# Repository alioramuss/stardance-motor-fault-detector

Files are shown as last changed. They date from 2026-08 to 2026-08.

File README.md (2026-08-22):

# Motor Fault Detector

An edge-AI predictive maintenance system. An accelerometer on a small motor
streams vibration to a laptop, where a machine-learning model decides in real
time whether the motor is running healthy or has developed a fault.

Built for the [Stardance Challenge 2026](https://stardance.hackclub.com)
(NASA × Hack Club × AMD × GitHub).

---

## The problem

When a motor develops a mechanical fault — a bearing wearing out, a rotor going
out of balance — it changes how it vibrates long before it fails. Industry
catches this with condition monitoring: sensors on the machine, software
watching for the signature of a fault. The equipment that does it costs
thousands.

This is the same idea for about £15, using a hobbyist accelerometer and a
laptop.

---

## Hardware

| Part | Role |
|---|---|
| Arduino Uno Rev3 | Samples the sensor and streams over USB |
| MPU-6050 (GY-521) | 3-axis accelerometer, ±2 g range, 16384 counts per g |
| USB desk fan | The motor under test |
| Breadboard + jumpers | |

Wiring — the Uno's I²C lives on A4/A5 and cannot be moved:

| MPU-6050 | Uno |
|---|---|
| VCC | 5V |
| GND | GND |
| SDA | A4 |
| SCL | A5 |

**Fault injection.** A small weight taped to one fan blade creates a rotor
imbalance — the most common mechanical fault in rotating machinery, and one
that produces a clear vibration signature at the rotation frequency.

**Sensor mounting.** The MPU-6050 is fixed to the fan body with double-sided
tape rather than a printed bracket. This is a known weakness: the sensor's
position shifted between the first two recordings, which is why the healthy and
faulty datasets are not perfectly comparable. A printed holder is planned, and
would be the single biggest improvement to data quality.

A full CAD assembly of the build is in [`CAD/`](CAD/), as STEP and STL.

---

## How it works

```
MPU-6050 ──I²C──> Arduino Uno ──USB serial──> browser
  200 Hz            timestamped CSV            ├─ 1 s rolling window
                    115200 baud                ├─ spectral features (FFT)
                                               ├─ neural network
                                               └─ HEALTHY / FAULT
                                                        │
                              LED alarm <──serial───────┘
```

The Uno does no inference. With 2 KB of RAM it cannot hold a neural network, so
it acts purely as a sensor node — a real constraint that shaped the design, not
a shortcut.

### Sampling

`firmware/motor_sensor.ino` samples all three axes at a fixed **200 Hz** and
prints `timestamp,ax,ay,az` at 115200 baud. The loop is timed with `micros()`
rather than `delay()` so the interval stays constant; the FFT downstream is
meaningless if the sample rate wanders.

200 Hz gives 100 Hz of usable bandwidth, comfortably above the fan's ~37.5 Hz
rotation frequency.

### Data collection

`tools/capture.ps1` reads the serial port and writes CSV. No extra software is
required — it uses `System.IO.Ports`, which ships with Windows.

Two 60-second recordings, 12,000 samples each: fan normal, and fan with the
weight attached. Each was split into twelve 5-second files so the training and
test sets could be split at the sample level.

### Features and model

Built in [Edge Impulse](https://edgeimpulse.com):

| Setting | Value |
|---|---|
| Window | 1000 ms |
| Stride | 500 ms (50% overlap) |
| Processing | Spectral Analysis, FFT length 64 |
| Classifier | Dense network, 111 input features |
| Training windows | 170 (90 faulty, 80 healthy) |

Spectral Analysis matters here for a specific reason: it removes the DC
component before the FFT. Without that, the model could learn *which way the
sensor is tilted* — gravity dominates the raw signal at roughly 16,000 counts,
while the vibration is a few thousand. Stripping DC forces it to use the
frequency content, which is what a fault actually changes.

### Deployment

The model is exported as a **WebAssembly** build and runs in the browser. The
dashboard reads the serial port directly through the Web Serial API, so
inference happens on the same machine with no server and no cloud call.

---

## Results

### Fan rotation frequency

The FFT shows a clear peak at **37.5 Hz — about 2,250 rpm.** The fan's speed,
measured with an accelerometer and some maths rather than a tachometer.

### Raw separation, before any ML

Standard deviation of the X axis:

| Condition | sd (counts) |
|---|---|
| Healthy | 2,507 |
| Imbalanced | 3,875 |

A 55% increase. The fault is visible in the raw data before a model touches it,
which is the right thing to check first.

### Classifier

| | Accuracy |
|---|---|
| First attempt, unnormalised features | 64.7% |
| With StandardScaler + 100 training cycles | 100% |
| Held-out test set | 5/5 samples, 44/44 windows |

The first attempt failed in an informative way: it classified almost everything
as faulty. The features range from log-spectral values near 6 to RMS values in
the thousands, and a network fed inputs on wildly different scales struggles to
converge. Normalising fixed it completely.

### Live performance

| Metric | Value |
|---|---|
| Sample rate sustained | 200/sec |
| Inference time | 0.3 ms |
| Decision latency | ~1 s (one window) |

---

## Honest limitations

**The 100% is not as good as it looks.** Both classes came from a single
continuous recording each. The training and test windows are therefore
near-neighbours from the same session — same fan, same position, same
afternoon. The test set measures whether the pipeline works, not whether the
model generalises.

In live use it detects the fault reliably but not every single time. That gap
between 100% on paper and imperfect in practice is the honest result, and it
comes directly from the single-session dataset.

**Two classes forces a choice.** Shown something it has never seen — a shaken
fan, a different motor, a fan switched off — the model must still answer
"healthy" or "faulty". It cannot say "this is something else". A real system
needs an anomaly class or a rejection threshold.

**One fault type, one machine.** Rotor imbalance on one USB fan. Nothing here
demonstrates transfer to bearing wear, or to a different motor.

### What would fix it

- Record many short sessions across different days, fan speeds and sensor
  placements, instead of one long one
- Add a "motor off" class so the model can't win by detecting whether the fan
  is running
- Add a second fault type — a rubbing or obstructed blade
- Measure the live detection rate properly: apply the fault N times, count how
  many are caught

---

## Running it

### Collect data

```powershell
# fan running in the condition you want to record
.\tools\capture.ps1 -Label healthy -Seconds 60
```

Writes `data/healthy.1.csv` … `data/healthy.12.csv`. Run it again with
`-Label faulty` after taping a small weight to one blade.

### Live detection

```powershell
cd model\browser
node serve.js
```

Then open `http://localhost:8000/live.html` in Chrome or Edge and click
**Connect Arduino**. Close the Arduino IDE's Serial Monitor first — only one
program can hold the port.

The dashboard shows the verdict and confidence, a live FFT spectrum with the
rotation peak marked, the vibration waveform with gravity removed, a history
strip of recent predictions, and an adjustable alarm threshold.

### Alarm threshold

The slider sets how much evidence is needed before declaring a fault, with
15 points of hysteresis so a marginal signal cannot flicker. Lower it and faults
are caught earlier at the cost of occasional false alarms — usually the right
trade for an alarm, since a missed failure costs more than a false one. Where
that line goes is an engineering decision, not something the model decides.

---

## Build notes

A few things that cost real time and might save someone else some.

**The Edge Impulse CLI will not install on Windows ARM64.** `npm install -g
edge-impulse-cli` fails because node-gyp cannot find a C++ compiler, and it
installs a broken shell that fails at runtime with MODULE_NOT_FOUND. Rather
than install several gigabytes of Visual Studio Build Tools, this project routes
around it entirely: CSVs are uploaded through Edge Impulse Studio's browser
uploader, and the model is deployed as WebAssembly instead of a compiled
library. Nothing is lost, and the whole toolchain stays compiler-free.

**Byte order in the accelerometer read.** The common Arduino idiom
`Wire.read() << 8 | Wire.read()` does not guarantee which `read()` executes
first, so it can silently return byte-swapped values. Reading each byte into its
own variable removes the gamble.

**Edge Impulse infers labels from filenames** up to the first dot, so
`healthy.1.csv` lands as *healthy*. Splitting each recording into numbered
chunks gives both automatic labelling and enough samples to split train/test.

---

## Repository

```
CAD/                      full assembly, STEP and STL
PCB/                      wiring diagram (no custom board — breadboard build)
firmware/                 Arduino sketch — samples at 200 Hz, drives the LED alarm
tools/capture.ps1         serial to CSV logger
data/                     recorded datasets, 5-second chunks
model/browser/            exported WebAssembly model, live dashboard, local server
docs/wiring.svg           wiring diagram
devlogs/                  build log
experiments/ultrasonic/   parked HC-SR04 non-contact sensing experiment
BOM.csv                   parts in the build
BOM-funding.csv           parts requested for the next phase
```

The `experiments/` folder is work that didn't make it into the main result —
kept because the reasoning is useful, and the write-up in
`experiments/ultrasonic/rig-design.md` explains why the approach hits a hard
physical limit.

---

## Licence

MIT.

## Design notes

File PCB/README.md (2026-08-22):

# PCB

**There is no custom PCB in this project.**

The build uses an Arduino Uno Rev3 with an MPU-6050 breakout module on a
solderless breadboard, so there are no board source files to publish. This
folder holds the wiring diagram instead, which serves the same purpose — it
shows exactly how the circuit is connected so someone can reproduce it.

`wiring-diagram.svg` — MPU-6050 to Arduino Uno.

| MPU-6050 | Uno | Note |
|---|---|---|
| VCC | 5V | via the breadboard's + rail |
| GND | GND | via the breadboard's − rail |
| SDA | A4 | I²C, fixed on the Uno |
| SCL | A5 | I²C, fixed on the Uno |

The only soldering in the build is the 8-way pin header onto the MPU-6050
module. The long side of the header goes into the breadboard.

A custom PCB would be a reasonable next step — it would remove the breadboard
as a source of intermittent contacts and let the sensor be mounted rigidly,
which is the main weakness of the current build.

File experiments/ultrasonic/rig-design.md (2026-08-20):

# Non-contact sensing experiment — design notes

**Question.** The MPU-6050 detects fan imbalance reliably, but it has to be
bolted to the machine. Can a £2 HC-SR04 ultrasonic rangefinder detect the same
fault without touching anything — and if so, at what angle and standoff?

**Why it's worth doing.** Contact sensors are the standard answer in condition
monitoring, but they need mounting, wiring and access. Non-contact sensing is
the interesting frontier, and knowing precisely *where a cheap sensor stops
working* is a legitimate result. This experiment can fail and still be worth
writing up — as long as the failure is characterised rather than hand-waved.

---

## The honest physics, up front

Work out whether this can possibly succeed before running it, because the answer
shapes what you measure.

**Sample rate.** The HC-SR04 needs roughly 40–60 ms between triggers or the
previous echo is still ringing when the next arrives. That caps you at about
**25 Hz**. Your fan spins at **37.5 Hz**.

Nyquist says you need to sample above 75 Hz to reconstruct a 37.5 Hz signal.
You are sampling at a third of that. The wobble will **alias** — a 37.5 Hz
motion sampled at 25 Hz folds down to |37.5 − 25| = **12.5 Hz**. So you cannot
take an FFT of the ultrasonic data and read the rotation frequency off it. Any
peak you see there is an artefact.

**Resolution.** The HC-SR04 quantises to about 3 mm, with a few mm of noise. A
small fan's housing displacement under imbalance is likely well under 1 mm.

**Therefore:** don't try to reconstruct the vibration waveform. Measure the
**spread of the readings** — standard deviation, peak-to-peak, missed-echo rate.
Undersampled noise is still noise, and if the housing moves more when
unbalanced, the distribution of readings should widen even when the timing is
hopeless. That is the hypothesis worth testing.

**Predicted outcome:** marginal to negative for a small USB fan. If you want it
to have a chance, see *Improving the odds* below.

---

## Wiring

Everything shares one ground.

| From | To | Note |
|---|---|---|
| MPU-6050 VCC / GND | 5V / GND | stays bolted to the fan — this is the reference |
| MPU-6050 SDA / SCL | A4 / A5 | I²C, fixed on the Uno |
| HC-SR04 VCC / GND | 5V / GND | mounted on the servo horn |
| HC-SR04 TRIG | D7 | |
| HC-SR04 ECHO | **D2** | must be D2 or D3 — external interrupt |
| Servo signal | D9 | |
| Servo V+ | **external 5V** if you have one | see below |
| Servo GND | GND, shared | |

**Servo power.** A moving servo pulls hundreds of milliamps and can spike over
an amp. Through the Uno's regulator that sags the 5 V rail, and the MPU-6050
reads the sag as motion — a fault that isn't there. A USB power bank or 4×AA
pack fixes it. If you have neither, the sketch detaches the servo after each
move so it draws nothing while recording. If the HC-SR04 droops under its own
weight when detached, set `HOLD = true` in the sketch and accept the noise, or
brace the arm.

**Aim.** Point the rangefinder at a flat part of the fan body, 5–20 cm away.
Ultrasonic sensors need a surface roughly perpendicular to the beam; angled or
soft surfaces scatter the echo and you'll see a high missed-echo rate.

---

## Two embedded problems the sketch solves

**`pulseIn()` would destroy the sample timing.** The standard HC-SR04 example
blocks for up to 30 ms waiting for the echo. In a 5 ms sampling loop that's six
missing accelerometer samples per ping, which corrupts the FFT and breaks the
model. Instead the trigger is fired and forgotten, and the echo is timed by an
interrupt on D2. Nothing blocks, and the 200 Hz cadence is untouched.

**A holding servo injects electrical noise** into the sensor it's meant to be
carrying. `attach()` → move → settle → `detach()`.

Both are worth a line in the write-up. They're real constraints with standard
answers, and showing you anticipated them reads better than showing clean data.

---

## Protocol

Send `U` and the rig sweeps five angles — 60°, 75°, 90°, 105°, 120° — recording
10 seconds at each with both sensors running simultaneously. Accelerometer at
200 Hz is the reference truth; rangefinder at ~25 Hz is the thing on trial.

Run the whole sweep twice:

```powershell
.\sweep.ps1 -Condition healthy    # fan clean
# add the weight to one blade, nothing else changes
.\sweep.ps1 -Condition faulty
```

Critically: **do not move anything between the two runs except the weight.**
The servo returns to each angle itself, so the geometry is repeatable — that's
the whole reason the servo is in this experiment rather than a bit of Blu Tack.

Output, per condition per angle:

- `<condition>.a<angle>.acc.csv` — `ax,ay,az`
- `<condition>.a<angle>.dist.csv` — `t_ms,mm` (`-1` = no echo returned)

---

## Analysis

For each angle, compare healthy against faulty on:

1. **Standard deviation of distance** — the main test. Does the spread widen?
2. **Peak-to-peak range** — more sensitive to occasional large excursions
3. **Missed-echo rate** — a vibrating surface scatters echoes, so *more misses*
   under fault is itself a signal, and an unexpected one
4. **Accelerometer RMS at the same moment** — the reference. Confirms the fault
   really was present, so a null ultrasonic result means "the sensor can't see
   it", not "there was nothing to see"

That fourth one is what makes this a controlled experiment rather than a guess.

A separation ratio above about 1.5× on any measure is a real effect at this
noise level. Below about 1.2× and you're reading tea leaves.

---

## Improving the odds

If the first sweep shows nothing, these are legitimate escalations, in order:

1. **More weight.** A bigger imbalance means more displacement. Characterising
   *how much* imbalance is needed before the ultrasonic sees it is arguably a
   better result than a yes/no — it gives you a detection threshold.
2. **Mechanical amplification.** Tape a light card to the fan body as the
   target surface. It acts as a lever, so a small housing movement becomes a
   larger movement at the card. This is a real technique, not a cheat — say so
   in the write-up.
3. **Closer standoff.** Shorter range means shorter echo flight time and less
   variance. Don't go below about 3 cm, the sensor's minimum.
4. **Softer mount for the fan.** A fan on foam moves more than one clamped to a
   desk. Arguably more realistic too — real machines sit on mounts.

---

## What to write up either way

- The Nyquist argument, worked out **before** collecting data rather than as an
  excuse afterwards
- The interrupt-driven ranging, and why `pulseIn()` was unusable
- A table of separation ratios by angle, for both sensors
- A clear statement of the detection threshold — the imbalance below which the
  non-contact channel stops working

A characterised limitation is a result. "It didn't work" is not.

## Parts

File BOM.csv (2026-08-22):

part | description | status | qty | unit_price_usd | total_usd | notes
Arduino Uno Rev3 | ATmega328P board — samples the sensor and streams over USB | owned | 1 | 12.00 | 12.00 | Sensor node only; 2 KB RAM too small for on-device inference
MPU-6050 module (GY-521) | 3-axis accelerometer breakout — I2C | owned | 1 | 3.00 | 3.00 | +/-2g range at 16384 counts per g
Breadboard 400 point | Solderless prototyping board | owned | 1 | 3.00 | 3.00 | Power and ground on the rails
Jumper wires male-to-male | VCC GND SDA SCL plus rail feeds | owned | 6 | 0.10 | 0.60 | From a standard 30-wire pack
Pin header 2.54mm 8-way | Soldered to the MPU-6050 module | owned | 1 | 0.20 | 0.20 | Long side goes into the breadboard
USB fan 5V | The motor under test | owned | 1 | 5.00 | 5.00 | Rotation measured at 37.5 Hz (~2250 rpm)
USB A to B cable | Powers and connects the Uno to the laptop | owned | 1 | 2.00 | 2.00 | Usually supplied with the Uno
Double-sided foam tape | Fixes the accelerometer to the fan body | owned | 1 | 1.00 | 1.00 | Known weakness — a printed bracket is planned
Small adhesive weight | Induces rotor imbalance for the faulty class | owned | 1 | 0.00 | 0.00 | Folded tape or blu-tack
Small brushed DC motor with fan blade | Second machine to test whether the model transfers beyond the original fan | requested | 1 | 6.00 | 6.00 | Biggest open question in the project — does it generalise
ESP32-C3 development board | Target for on-device inference if the Uno's 2 KB proves too small | requested | 1 | 7.00 | 7.00 | Only needed if the shrunk model will not fit the ATmega328P
MPU-6050 module (GY-521) | Second sensor so both machines can be instrumented at once | requested | 1 | 3.00 | 3.00 | Same part as the existing one
Aluminium angle bracket and M3 screws | Rigid repeatable sensor mount | requested | 1 | 4.00 | 4.00 | Fixes the tape problem that compromised the first dataset
Calibrated grub weight set | Known masses for repeatable imbalance | requested | 1 | 3.00 | 3.00 | Lets the detection threshold be measured rather than estimated
Double-sided foam mounting tape | Sensor to machine coupling for the second machine | requested | 1 | 1.00 | 1.00
 |  | owned subtotal |  |  | 26.80 | Parts already in the working build
 |  | requested subtotal |  |  | 24.00 | Parts needed for the next phase — this is the funding ask

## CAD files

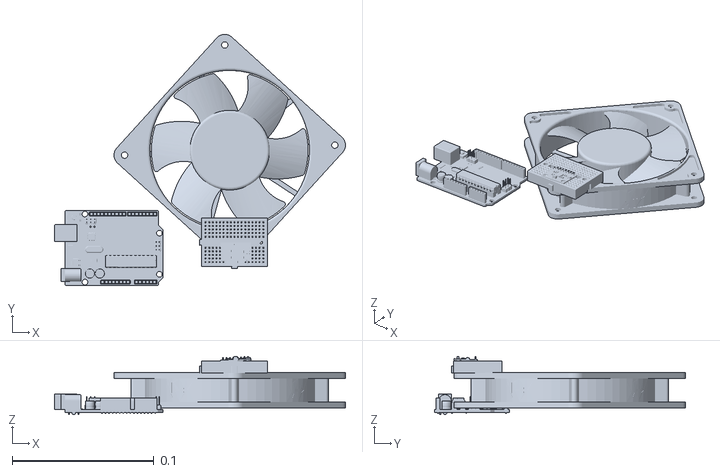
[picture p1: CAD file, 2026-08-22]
CAD/motor-fault-detector-assembly.stl
0.205 x 0.177 x 0.041

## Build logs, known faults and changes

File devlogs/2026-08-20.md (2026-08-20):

# Devlog — 20 August 2026

*(Draft — rewrite in your own words before posting. Stardance wants a human voice.)*

## Added to the dashboard

Three things on top of yesterday's live detector:

- **A live frequency spectrum.** 256-point FFT with a Hann window, so you can
  watch the 37.5 Hz rotation peak in real time. It shows the peak in Hz and rpm,
  and turns red when the verdict is FAULT.
- **A physical alarm.** The browser now sends `F` or `H` back down the serial
  line and the Arduino lights its onboard LED. So the fault shows up on the
  hardware, not just on screen.
- **An adjustable alarm threshold**, with 15 points of hysteresis so a marginal
  signal can't flicker between states. Lowering it catches faults earlier at the
  cost of the odd false alarm — which is usually the right trade for an alarm,
  because a missed failure costs more than a false one.

## Tried adding a second sensor, and it didn't work out

The idea: use an HC-SR04 ultrasonic rangefinder as a **non-contact** channel
alongside the accelerometer, with the servo sweeping it to find the best angle.
Can a £2 rangefinder see a fault that a contact sensor sees?

Most of the afternoon went on getting no echo at all. Two causes, both stupid,
both worth writing down:

1. **Trig and Echo were swapped.** Echo has to be on D2 or D3 on an Uno,
   because those are the only pins that can raise the interrupt I'm using to
   time the pulse without blocking.
2. **The breadboard power rail wasn't connected to anything.** I'd plugged the
   sensor's VCC into the + rail, but nothing was feeding the rail from the Uno.
   Then when I moved it next to the 5V wire it still didn't work — because holes
   *side by side* on a breadboard are separate circuits. Only the group of five
   running across is one connection. I'd been building on that misunderstanding
   for a while.

Once powered it worked immediately — 112 mm, ±1 mm of noise, 0% missed echoes.

Then the servo never turned, so all five "angles" in my sweep were the same
physical position. Ran both conditions anyway.

## Why I threw the result away

The numbers looked brilliant. Ultrasonic spread went from 1.2 mm healthy to
12.6 mm faulty — a 10.7× separation. Better than I expected.

Then I checked the accelerometer, which was recording at the same time as a
reference. Vibration during the "healthy" run was sd **52**, against **3832**
for faulty. My earlier healthy recordings with the fan definitely running were
around 2500.

**The fan was switched off during the healthy run.** So the 10.7× wasn't
balanced versus unbalanced — it was fan-off versus fan-on. The result was
meaningless.

Recording both sensors simultaneously is the only reason I caught it. If I'd
only logged the ultrasonic I'd have written up a fake result and believed it.

The raw distances say something else too: the faulty readings scatter from 65 to
216 mm, which isn't sub-millimetre housing wobble — that's the blades chopping
through the beam. Real effect, but not the one I was testing for.

Parking the ultrasonic here. The core accelerometer project works and I'd rather
finish that properly.

## Also today

Wrote the README, including an honest limitations section: the 100% test
accuracy is inflated because both classes came from a single continuous
recording each, and live detection is good but not perfect.

## Next

- Tidy the repo and push
- Re-record the dataset across several separate sessions
- Add a "motor off" class so the model can't cheat by detecting whether the fan
  is running at all

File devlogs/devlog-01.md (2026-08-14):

# Devlog 1

**14 Aug 2026** 

## Where the project is

Building a motor fault detector. An accelerometer goes on a small USB fan, and a model reads the vibration and says whether the fan is running fine or running unbalanced. Same idea as predictive maintenance on real motors, just small enough to fit on my desk.

The Uno is only the sensor. It samples the accelerometer and sends the numbers over serial, and the model runs on my laptop. I looked at doing inference on the Uno itself but it doesn't have the memory for it, so splitting it this way was the only real option.

## Today

Last parts arrived (MPU-6050, breadboard, USB fan). I now have everything I need, nothing left on order.

Installed the Arduino IDE and it picked up the Uno straight away. I was expecting to waste an hour on drivers or COM ports and didn't, so that was a nice surprise.

Then I tested the serial link before touching the sensor at all. Uploaded a sketch, watched the numbers come through the serial monitor, checked the upload and read loop worked properly. I wanted this working first because everything else depends on it. If serial is unreliable then debugging the sensor later becomes impossible, since you can't tell whether the sensor is wrong or the connection is.

I also wanted to check the fault is actually there before I spend weeks trying to detect it. Ran the fan clean, then added an imbalance, and I could feel the difference straight away. Big obvious wobble through the whole body of the fan.

That's useful but it also creates a problem. If I can feel it with my hand, then a simple threshold on vibration size would catch it too, and then the ML part of the project is pointless. So I need more than healthy vs broken. I'm going to plan for imbalance at two or three different severities, and ideally a second type of fault, so the model has to do something a threshold can't. Better to design the data collection around that now than redo it later.

## Blocked

The MPU-6050 came with the pin header not soldered on. Board and pin strip are two separate things in the bag, so I can't put it in the breadboard yet and can't collect any data.

No soldering iron here, so I'm taking it to a repair shop tomorrow. Bringing the board, the header, and the breadboard so they can check it lines up. Pins go on the opposite side to the chip, short ends down, so it sits flat. Getting all 8 done even though I only use 4, because the extra ones hold it in place.

When I get it back I'll check the joints and check no two pins are bridged. If SDA and SCL are touching, the sensor just won't appear at all, and that looks exactly like a dead board, so I'd rather find it with my eyes than spend an evening debugging code that was never broken.

## Next

- Soldering done, joints checked
- Wire the MPU-6050 over I2C and confirm the Uno finds it
- Get 3-axis data streaming at a stable sample rate
- Work out what that sample rate should be. Needs to be well above twice the fan's rotation speed or the vibration signature gets aliased
- Decide the fault classes properly
- Build a proper mount for the sensor

Last thing. The mount is more important than it looks. If the sensor sits slightly differently each time I record, the model ends up learning how I taped it down instead of learning the fault, and whatever accuracy I get at the end means nothing. So I want to fix the position once and leave it alone for the whole of data collection.

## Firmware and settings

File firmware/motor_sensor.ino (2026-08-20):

// Motor fault detector — sensor node
// Streams ax,ay,az at 200 Hz and lights the onboard LED when the
// dashboard sends 'F' (fault) back down the serial line. 'H' clears it.

#include <Wire.h>

const uint8_t  MPU         = 0x68;
const uint8_t  LED_PIN     = LED_BUILTIN;   // pin 13, already on the board
const unsigned long INTERVAL_US = 5000;     // 200 samples/sec

unsigned long next_us;

void setup() {
  pinMode(LED_PIN, OUTPUT);
  digitalWrite(LED_PIN, LOW);

  Serial.begin(115200);
  Wire.begin();
  Wire.setClock(400000);

  Wire.beginTransmission(MPU);
  Wire.write(0x6B);      // power management
  Wire.write(0);         // wake the sensor
  Wire.endTransmission(true);

  Serial.println("timestamp,ax,ay,az");
  next_us = micros();
}

void loop() {
  // --- keep a steady 200 Hz -------------------------------------------
  next_us += INTERVAL_US;
  while ((long)(micros() - next_us) < 0) { }

  // --- listen for a verdict from the dashboard ------------------------
  while (Serial.available() > 0) {
    char c = Serial.read();
    if (c == 'F') digitalWrite(LED_PIN, HIGH);
    else if (c == 'H') digitalWrite(LED_PIN, LOW);
  }

  // --- read the accelerometer -----------------------------------------
  Wire.beginTransmission(MPU);
  Wire.write(0x3B);      // first accelerometer register
  Wire.endTransmission(false);
  Wire.requestFrom((uint8_t)MPU, (uint8_t)6, (uint8_t)true);

  uint8_t xh = Wire.read(), xl = Wire.read();
  uint8_t yh = Wire.read(), yl = Wire.read();
  uint8_t zh = Wire.read(), zl = Wire.read();

  int16_t ax = (int16_t)((xh << 8) | xl);
  int16_t ay = (int16_t)((yh << 8) | yl);
  int16_t az = (int16_t)((zh << 8) | zl);

  Serial.print(millis());  Serial.print(',');
  Serial.print(ax);        Serial.print(',');
  Serial.print(ay);        Serial.print(',');
  Serial.println(az);
}

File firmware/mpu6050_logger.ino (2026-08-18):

#include <Wire.h>

// ---- MPU-6050 registers (from the datasheet) ----
const uint8_t MPU_ADDR         = 0x68;
const uint8_t REG_PWR_MGMT_1   = 0x6B;  // sleep control
const uint8_t REG_CONFIG       = 0x1A;  // low-pass filter
const uint8_t REG_ACCEL_CONFIG = 0x1C;  // measurement range
const uint8_t REG_ACCEL_XOUT_H = 0x3B;  // first accel data byte

const float LSB_PER_G = 8192.0;              // counts per 1g at +/-4g
const unsigned long SAMPLE_INTERVAL_MS = 5;  // 5ms = 200 samples/sec

unsigned long lastSample = 0;

void writeRegister(uint8_t reg, uint8_t value) {
  Wire.beginTransmission(MPU_ADDR);
  Wire.write(reg);
  Wire.write(value);
  Wire.endTransmission();
}

void setup() {
  Serial.begin(115200);
  Wire.begin();
  Wire.setClock(400000);

  writeRegister(REG_PWR_MGMT_1, 0x00);   // wake the sensor
  writeRegister(REG_CONFIG, 0x00);       // filter off
  writeRegister(REG_ACCEL_CONFIG, 0x08); // +/-4g range

  Serial.println("t_ms,ax_g,ay_g,az_g");
}

void loop() {
  unsigned long now = millis();

  if (now - lastSample < SAMPLE_INTERVAL_MS) return;
  lastSample = now;

  Wire.beginTransmission(MPU_ADDR);
  Wire.write(REG_ACCEL_XOUT_H);
  Wire.endTransmission(false);

  Wire.requestFrom(MPU_ADDR, (uint8_t)6, (uint8_t)true);
  if (Wire.available() < 6) return;

  uint8_t xHigh = Wire.read(), xLow = Wire.read();
  uint8_t yHigh = Wire.read(), yLow = Wire.read();
  uint8_t zHigh = Wire.read(), zLow = Wire.read();

  int16_t rawX = (int16_t)((xHigh << 8) | xLow);
  int16_t rawY = (int16_t)((yHigh << 8) | yLow);
  int16_t rawZ = (int16_t)((zHigh << 8) | zLow);

  Serial.print(now);                 Serial.print(",");
  Serial.print(rawX / LSB_PER_G, 4); Serial.print(",");
  Serial.print(rawY / LSB_PER_G, 4); Serial.print(",");
  Serial.println(rawZ / LSB_PER_G, 4);
}

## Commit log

2026-08-14 Add devlog 1: parts arrived, serial verified, blocked on soldering
    Documented initial project details, progress, and next steps for the motor fault detector.
2026-08-18 Implement I2C scanner in i2c_scanner.ino
    Added I2C scanner functionality to detect devices on the I2C bus.
2026-08-20 Add dataset, capture tooling, trained model, live dashboard and docs
    [faulty.1.csv, faulty.10.csv, faulty.11.csv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]
2026-08-21 Add BOM for next phase: transfer testing and repeatable fault injection
    [BOM.csv]
2026-08-22 Add CAD assembly (STEP/STL), PCB wiring folder, build BOM
    [BOM-funding.csv, BOM.csv, motor-fault-detector-assembly.stl]
